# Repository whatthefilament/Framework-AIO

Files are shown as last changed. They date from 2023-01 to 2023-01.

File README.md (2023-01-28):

# Framework-AIO
3D Printable Case for Framework Laptop that converts it into an AIO style Desktop Computer

I've used as many OEM Framework parts as possible.

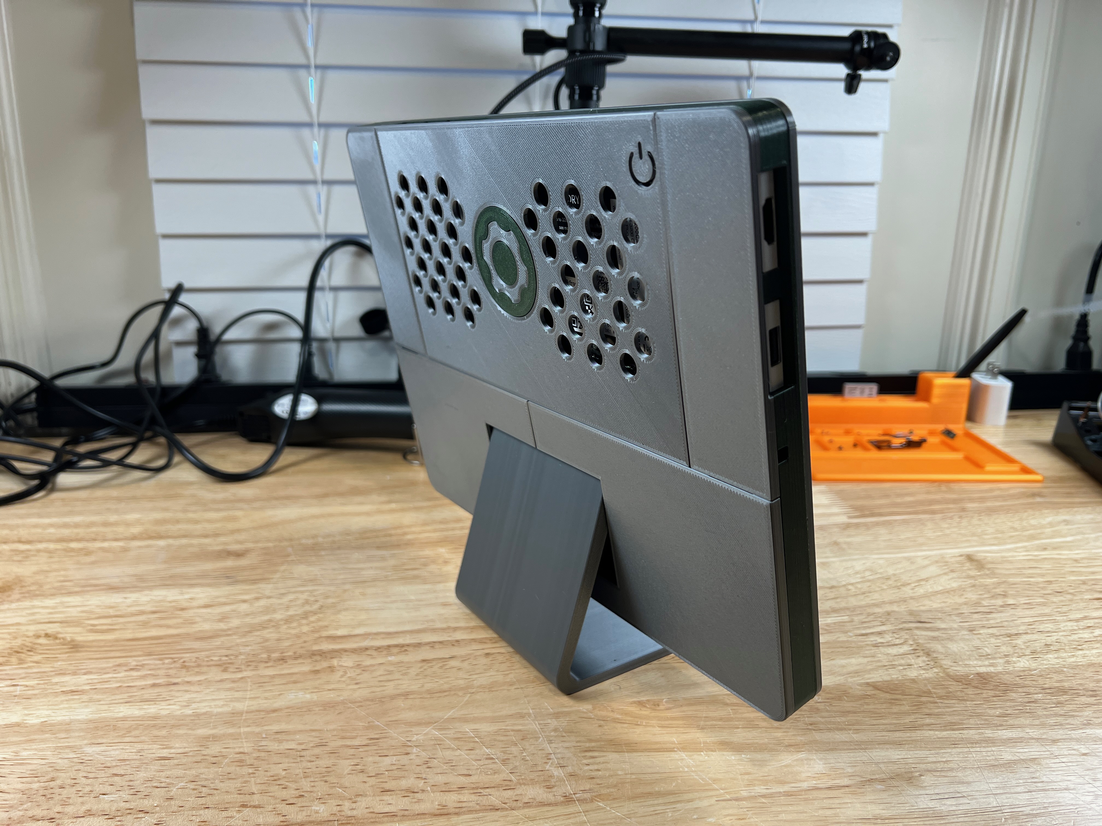
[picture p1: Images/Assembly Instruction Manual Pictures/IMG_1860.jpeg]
Side


## Assembly

[Build Instructions](https://www.instructables.com/Framework-AIO-Assembly/)

To help organize parts for this project, feel free to check out my [Framework parts tray](https://www.printables.com/model/253099-framework-parts-tray)

For assembly, you will need the following:

- 14 - M3 heat inserts (short)
- 10 - M3 x 4mm screws
- 4 - M3 x 8mm screws
- 1 - M2 x 6mm Self tap Screw
- 30 - 6mm x 3mm Magnets

- A small mallet/hammer to press in magnets (They are designed to be tight)
- M3 hex key
- Small head Phillips screwdriver (the one that comes with the Framework laptop works great)
- Soldering iron or other similar heat press insert tool
#
From the laptop itself you will need the following:

- Mainboard
- Expansion Cards
- Audio Board
- Wi-Fi Module
- Wi-Fi Antenna (Highly recommended that you buy a new one from Framework for the build, the antennas are very thin and break easily when attempting to remove from the display housing)
- Speakers
- Display
- Webcam and webcam ribbon cable
- Display Hinge (Specifically the left one with the L stamped onto it) I havent tried the new high weight hinges so I don't know if they work. I designed using the original hinges.
#
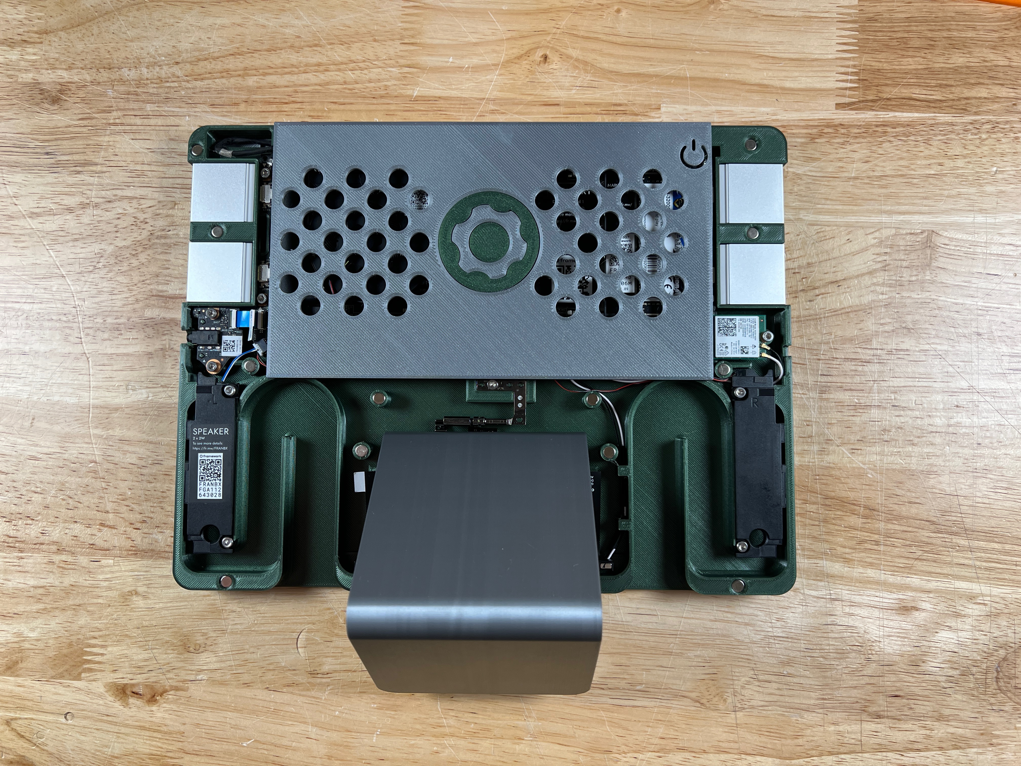
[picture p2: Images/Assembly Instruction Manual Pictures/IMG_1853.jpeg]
Open Back

#
## Print Settings:

I recommend printing all case parts of either ASA or ABS as this provides the best heat resistance. PETG may also work but I have not fully tested it. 

This case is designed to be printed at 0.2mm layer height with a 0.4mm nozzle.

No printed supports are needed. All holes have built-in supports. STLs are properly oriented for correct printing.

The main case has an overall dimension is 301.15mm x 231mm x 21. 

Thought many of the parts can be printed on a smaller printer. The main chassis and bezel will need a printer that can accommodate at least 301mm. 

## Mounting Options

In addition to the stock desk stand i've also included a 75mm VESA mount option for mounting on monitor arms.

I've uploaded the step files for the model as well, feel free to modify the design however you'd like. 

#
<br />This work is licensed under a <a rel="license" href="http://creativecommons.org/licenses/by-nc-sa/4.0/">Creative Commons Attribution-NonCommercial-ShareAlike 4.0 International License</a>.
#
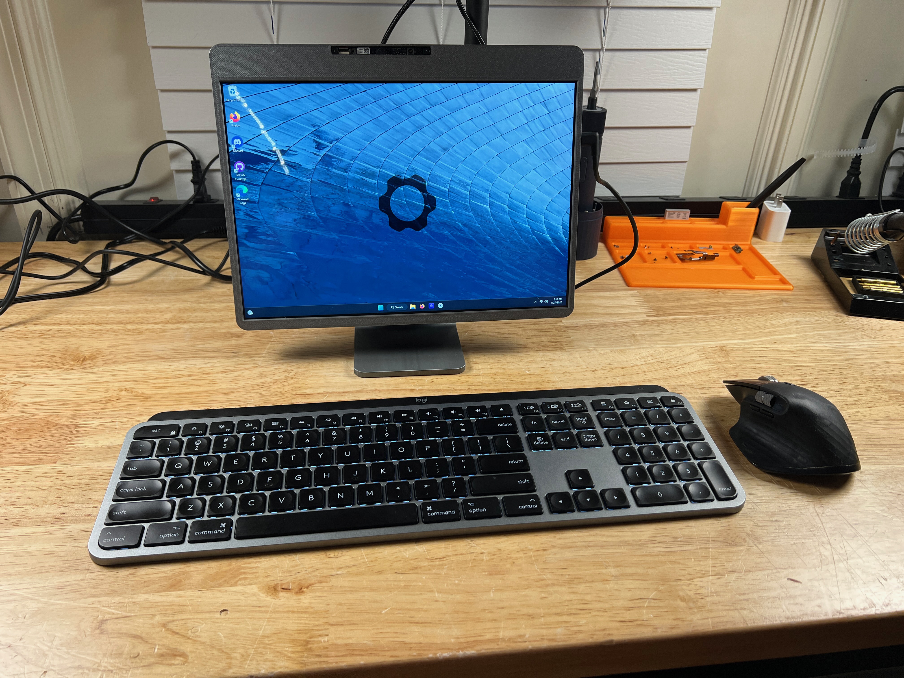
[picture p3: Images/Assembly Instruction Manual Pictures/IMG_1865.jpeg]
Running

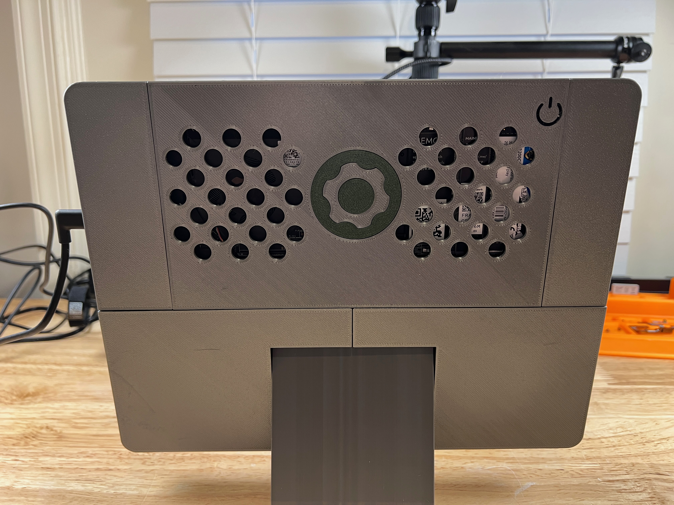
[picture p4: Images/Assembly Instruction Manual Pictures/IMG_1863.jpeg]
Back

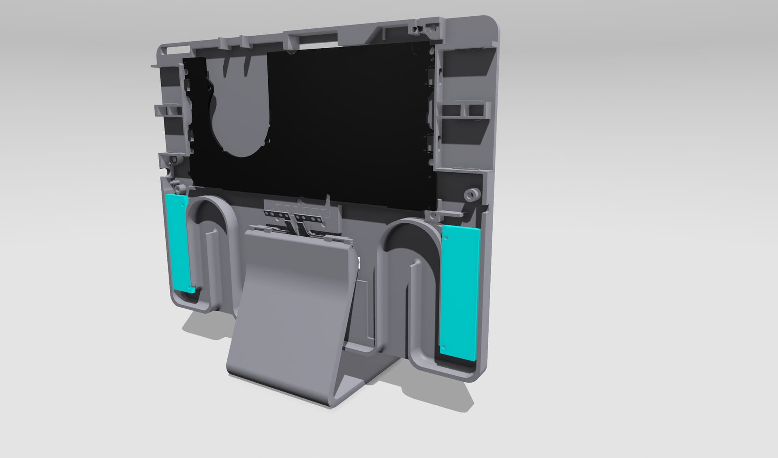
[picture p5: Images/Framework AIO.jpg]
Back Render

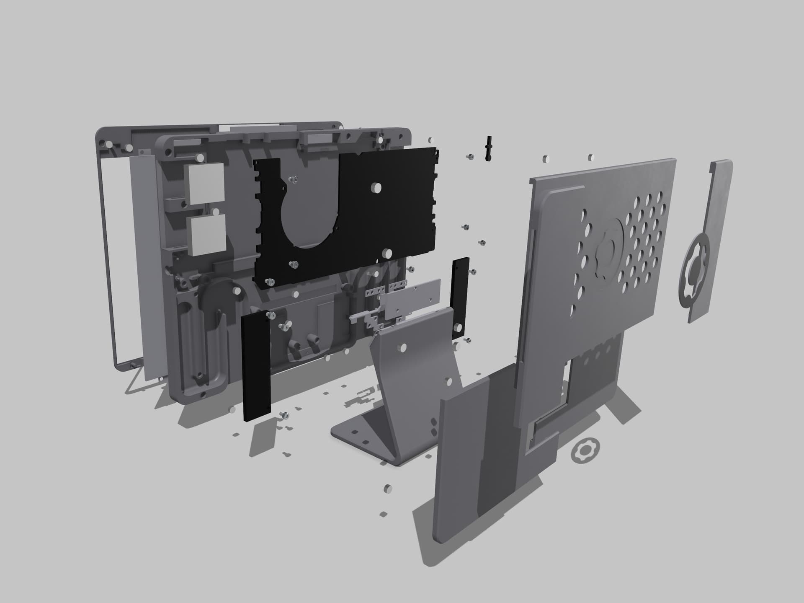
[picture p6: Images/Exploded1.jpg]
Exploded 1

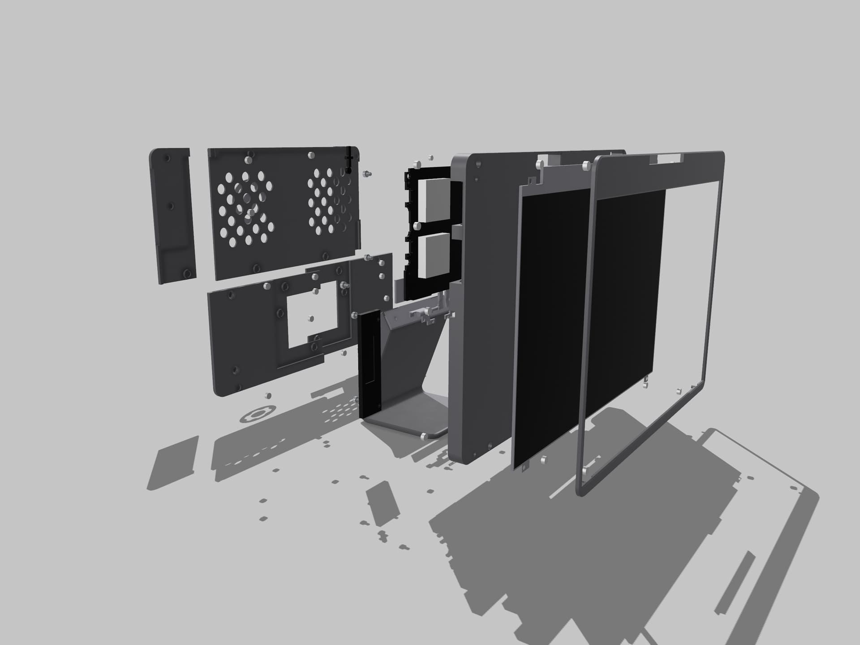
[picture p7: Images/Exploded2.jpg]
Exploded 2


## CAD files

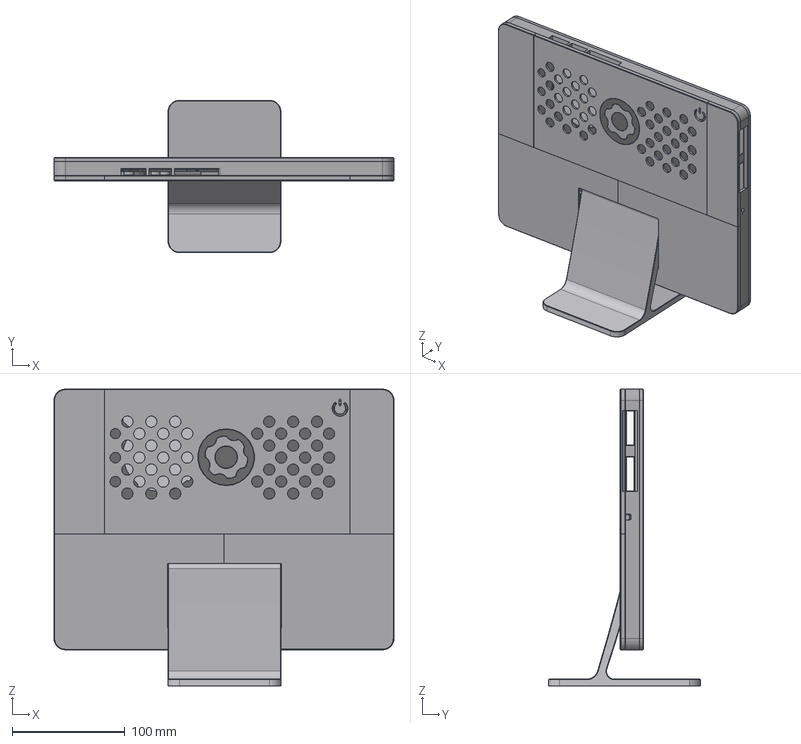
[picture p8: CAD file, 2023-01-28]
STEP/Framework AIO.step
301.2 x 135.0 x 262.9 mm
Back Panels
Stand
Back Panel Magnets (1)
Back Panel Magnets
Display Magnets
Hinges
Expansion Cards
Speakers

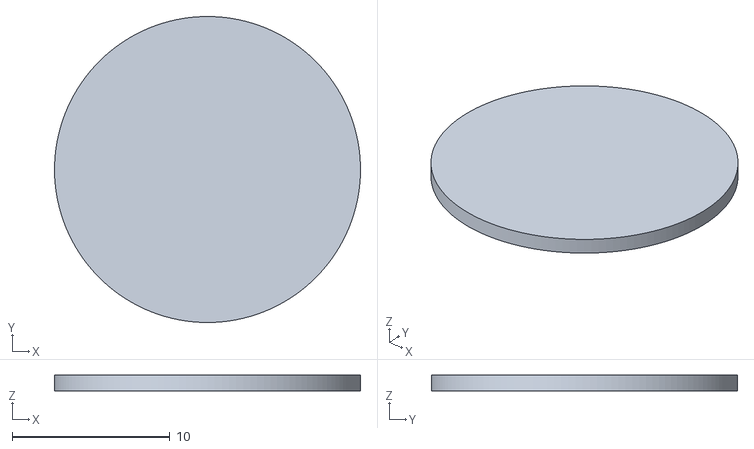
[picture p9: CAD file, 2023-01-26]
STLs/Back Panel/Logo Inner.stl
19.4 x 19.4 x 1.00

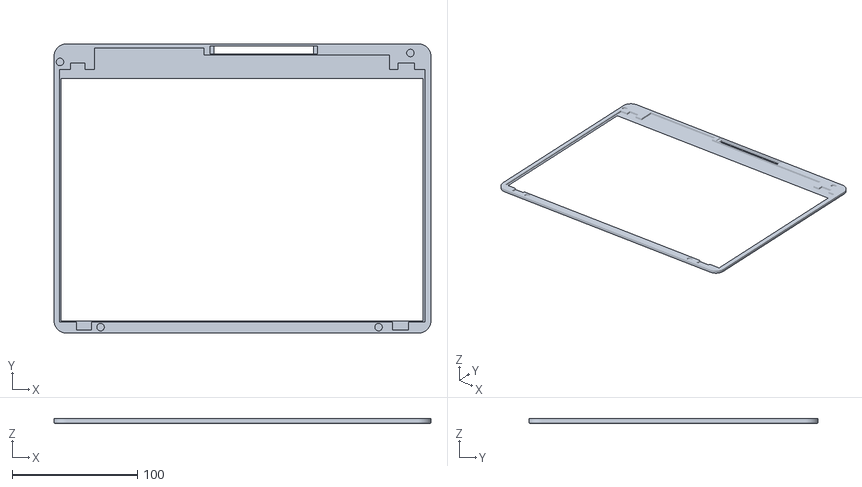
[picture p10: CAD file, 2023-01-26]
STLs/Display Bezel.stl
301.1 x 231.0 x 3.60

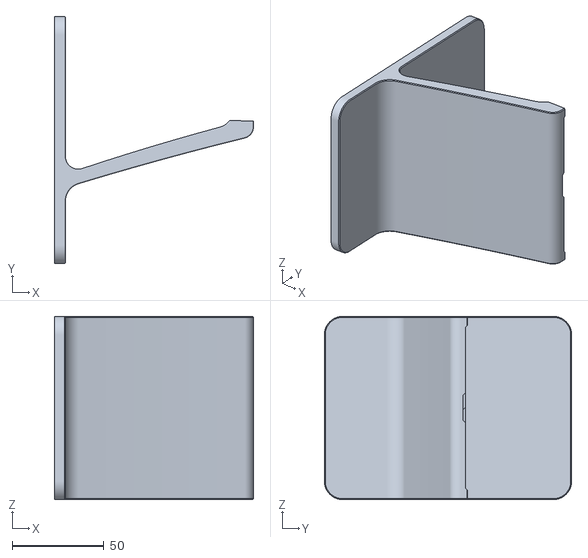
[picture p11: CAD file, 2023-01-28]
STLs/Stand Options/Desk Stand.stl
108.6 x 135.0 x 100.0

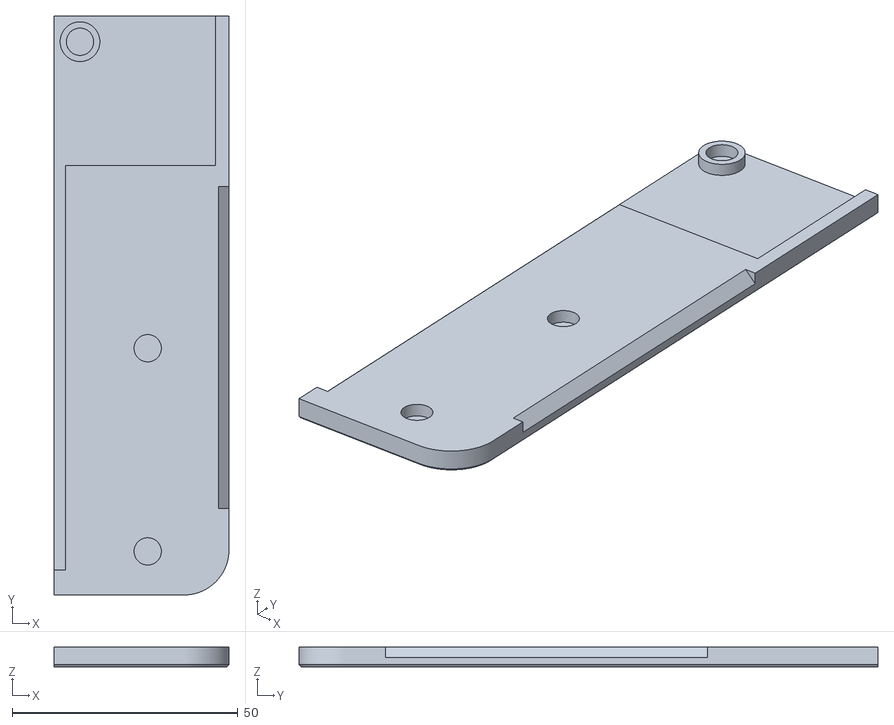
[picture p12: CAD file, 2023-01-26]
STLs/Back Panel/Upper Right Panel.stl
38.8 x 128.3 x 4.40

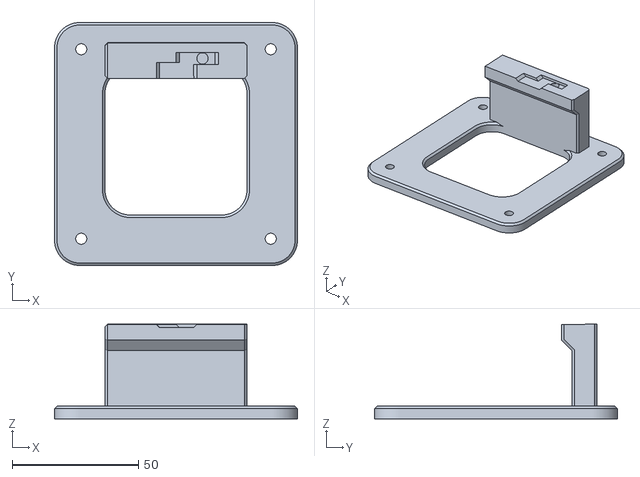
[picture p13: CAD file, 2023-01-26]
STLs/Stand Options/75mm VESA Mount.stl
96.2 x 96.2 x 37.4

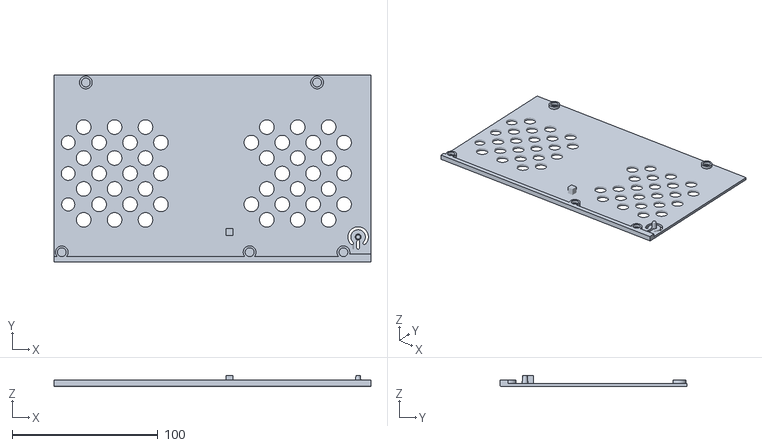
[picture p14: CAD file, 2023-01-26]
STLs/Back Panel/Center Panel.stl
217.5 x 128.3 x 7.50

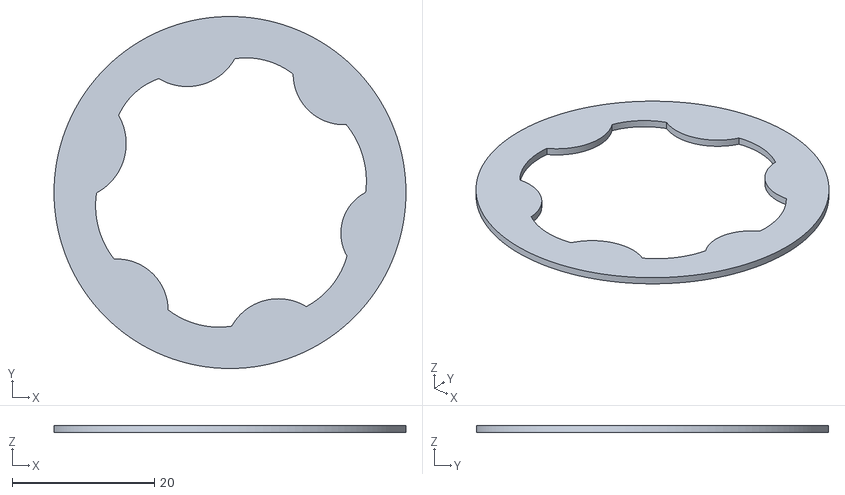
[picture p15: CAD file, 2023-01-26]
STLs/Back Panel/Logo Outer.stl
49.4 x 49.5 x 1.00

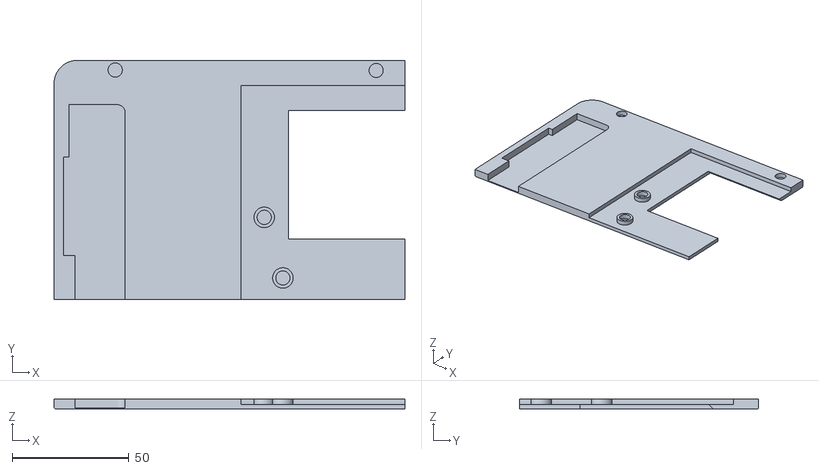
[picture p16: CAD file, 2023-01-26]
STLs/Back Panel/Lower Left Panel.stl
150.5 x 102.6 x 4.40

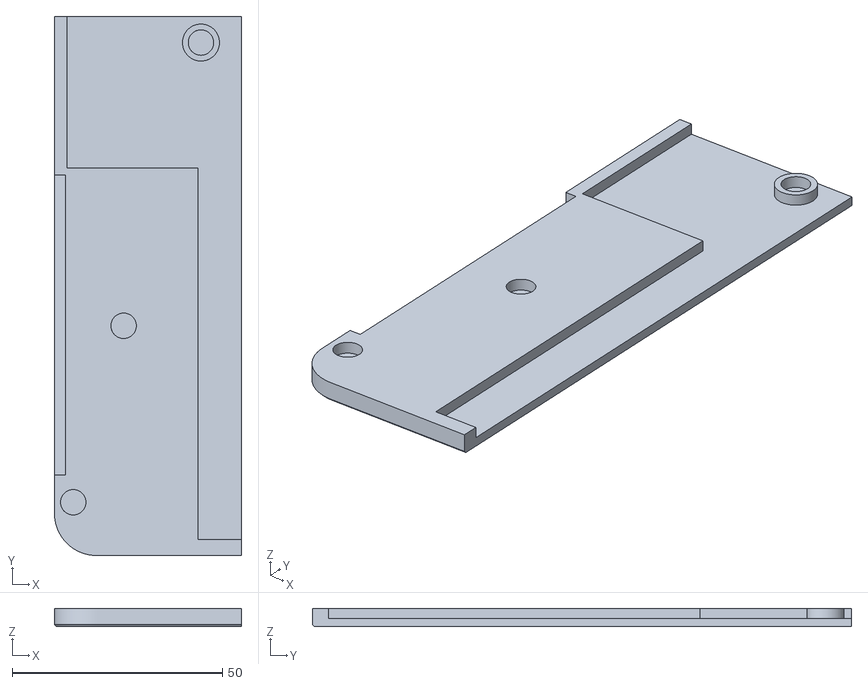
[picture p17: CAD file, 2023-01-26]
STLs/Back Panel/Upper Left Panel.stl
44.5 x 128.3 x 4.40

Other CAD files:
STLs/Back Panel/Lower Right Panel.stl

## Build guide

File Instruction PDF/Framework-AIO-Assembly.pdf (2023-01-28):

instructables

Framework AIO Assembly (http://www.instructables.com/Framework-AIO-Assembly/)

by whatthefilament (http://www.instructables.com/member/whatthefilament/)

3D Printable Case for Framework Laptop that converts it into an AIO style Desktop Computer

Supplies:
To help organize parts for this project, feel free to check out my [Framework parts tray] (https://www.printables.com/model/253099-framework-parts-tray)

For assembly, you will need the following:

- 14 - M3 heat inserts (short)
- 10 - M3 x 4mm screws
- 4 - M3 x 8mm screws
- 1 - M2 x 6mm self tapping screw
- 30 - 6mm x 3mm Magnets
- A small mallet/hammer to press in magnets (They are designed to be tight)
- M3 hex key
- Small head Phillips screwdriver (the one that comes with the Framework laptop works great)
- Soldering iron or other similar heat press insert tool

From the laptop itself you will need the following:
- Mainboard
- Expansion Cards
- Audio Board
- Wi-Fi Module
- Wi-Fi Antenna (Highly recommended that you buy a new one from Framework for the build, the antennas are very thin and break easily when attempting to remove from the display housing)
- Speakers
- Display
- Webcam and webcam ribbon cable

Framework AIO Assembly: Page 1

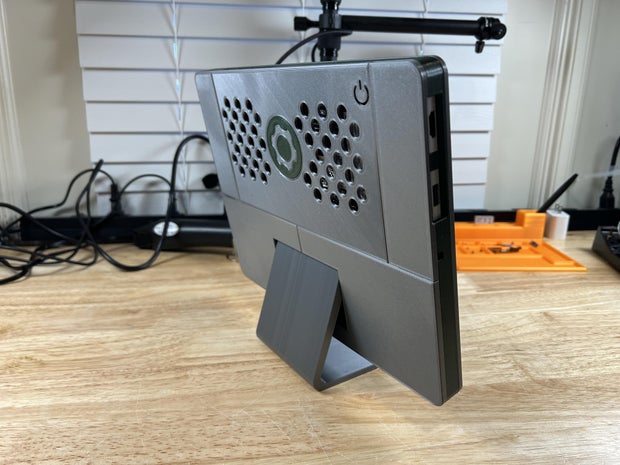
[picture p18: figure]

Step 1: Heatset Inserts
- Display Hinge (Speci<cally the left one with the L stamped onto it) I havent tried the new high weight hinges so I don't know if they work. I designed using the original hinges.

Using a soldering iron or other tool capable of setting a heat set insert place the 14 heatset inserts. ( 13 in the main chassis and 1 in the desktop stand. See each location highlighted in the images above.

Step 2: Magnets

Using 30 6x3mm magnets set a magnet in each of the highlighted spots from the images above.
Please remember to keep polarity in mind. When attaching the display bezel and back panelsthe polarity needsto be correct so that they aren’t repelled.
Note, each magnet mounting spot is designed to be snug enough that the magnets will hold in with friction. Depending on your printer you may need to add a dab of glue if the magnet doesn’t hold in place on its own.

Step 3: Add Display Panel and Webcam

Set the display panel face down into the bezel. Ensure each of the 4 tabs line up and sit properly in the frame.

After placing the display we will add the webcam module. To get correct orientation from the webcam output you will need to place it so that ribbon cable is point towards the top of the bezel and rapped back around.
If placed with the ribbon cable facing down the camera feed will be upside down and I haven’t found a way in Windows to rotate it.

Once placed in the bezel bend and route the ribbon cable as shown in the picture above. This will leave enough slack to connect the cable to the mainboard while not <lling up the back compartment with unnecessary cable.

Step 4: Attach Display to Chassis

Once the display and webcam are properly set in the bezel. Run the webcam cable in display cable through the holes highlighted above.

After pulling the cables through align the magnets and set the chassis down of the display. Everything should snap into place.
If the bezel doesn’t sit Bush you just need to pull the cables a little to get them to sit in their channels. There is not a lot of spare room so just play around with them till it sits right.

Step 5: Add Mainboard and Expansion Cards

Once everything is properly situated with the display bezel. Set the mainboard in the chassis as shown above making sure to align the audio board with its mounting studs. Everything should <t snug in place.

Before screwing down the mainboard. I suggest plugging in your expansion cards. They will help make sure everything is properly aligned.
If you’re struggling to get the expansion cardsto plug in feel free to cut out the alignment rails along the sides of each expansion slot on the chassis. They are designed to allow the expansion cardsto slide into the chassis asthey do in the laptop but depending on your printer calibration they can be tough. With them removed it becomes much easier to plug in the cards. They are just a bit looser and have the potential to harm the USB C slot mounted to the mainboard if torqued the wrong way.

After adding the mainboard and plugging in the expansion cards go ahead and screw down the mainboard, audio board and Wi-Fi module with the 8 M3x4mm screws highlighted in the picture above.

Step 6: Add Wi-Fi Antenna

Before setting the Wi-Fi antenna in the chassis. Start the M2x6mm self tapping screw to the middle antenna hole. Before screwing it into place route the antenna wiresthrough the retainers asshown in the picture above.

With the wires run you can now set the antenna module in place and screw fasten it.

After you fasten it, connect the white and black wires to their respective pins on the WiFi module. Be careful, the pins are delicate.

After all steps above are done, route the antenna wire slack as shown in the picture above to keep it safe and out of the way.

Step 7: Speakers

With the Wi-Fi installed and out of the way. We can now move on to the speakers.
Set the speakers into the chassis as show, each speaker is held in place with 2 M3x8mm bolts.
DO NOT OVER TIGHTEN THE SCREWS. THEY HAVE RUBBER GASKETS THAT WILL MANAGE VIBRATION. THE SCREWS ONLY NEED TO BE TIGHTENED DOWN ENOUGH SO THEY CLEAR THE BACK PANELS.
With the speakers mounted, run the cables as shown in the picture above and connect the speaker cable to the mainboard.
Ensure the speaker cable runs above the hinge mount but below the mainboard to keep from getting caught in the hinge.
Using a spudger or other similar tool (the framework screwdriver works great) push the wire coming out of the speaker on the right down below the speaker. We don’t want it to get caught between the chassis and panel when being snapped into place.

Step 8: Display Mount

At this point, all electrical components are installed in the chassis and we can move on to the display mount.

You can choose to use either the desk stand or the VESA mount. For this assembly, we will be using the desk stand.

Screw the hinge into the stand using an M3x4mm bolt as shown in the picture above. We want to start with the stand as we won't be able to access this side of the hinge when mounting in the case.

After it is attached, align the other side of the hinge with its mounting point in the center of the chassis and secure it in place with the last M3x4mm bolt.

Step 9: Back Panels

At this point, we have a functional computer but we still want it to look nice, so we can simply add the panels to the back letting the magnets align each panel into place with a satisfying snap! If you decided to print an accent inlay for the logo now would also be a good time to glue it into place.

Step 10: First Boot

We now have a beautifully assembled computer. Great job!

You can plug in any suGciently powered USB-C cable to power the machine. Using the power button located on the back the machine will boot.

The only problem we have now is the display will be upside down. To <x this we can simply go into the settings menu on windows, display settings and set the orientation to Bipped.

Step 11: Complete!

Great job! You have completed the assembly of your Framework AIO. I hope you like it! Let me know if you have any suggestions or improvements I can make to future iterations.

Special thanks to HJA for her help!

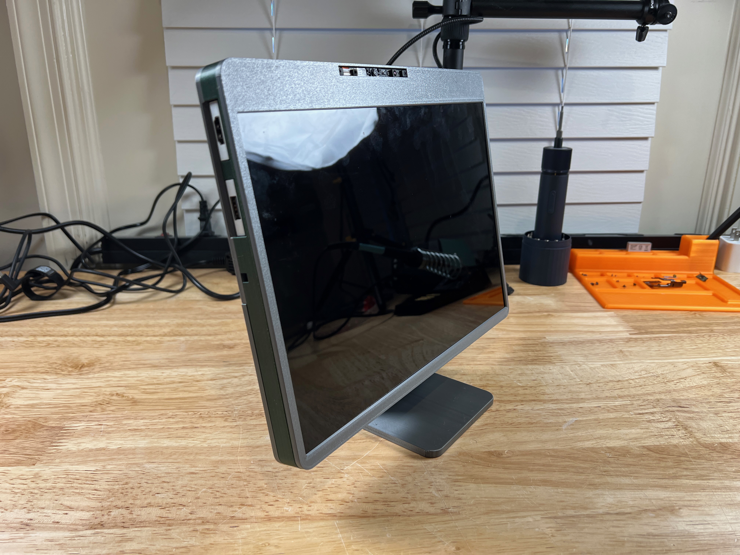
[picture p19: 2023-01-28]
Images/Assembly Instruction Manual Pictures/IMG_1859.jpeg

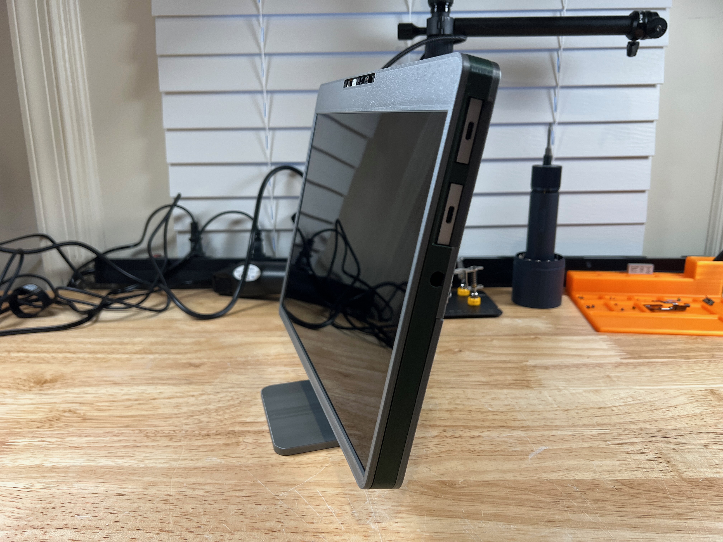
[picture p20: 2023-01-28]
Images/Assembly Instruction Manual Pictures/IMG_1862.jpeg

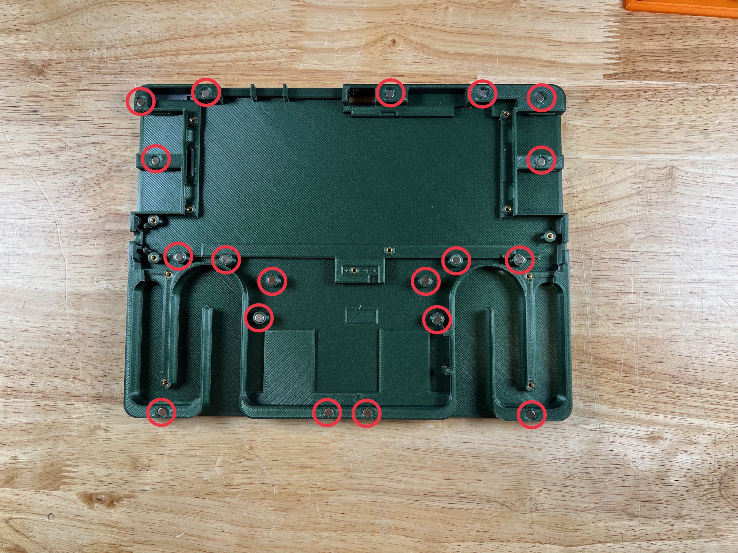
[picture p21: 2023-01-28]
Images/Assembly Instruction Manual Pictures/IMG_1828.jpeg

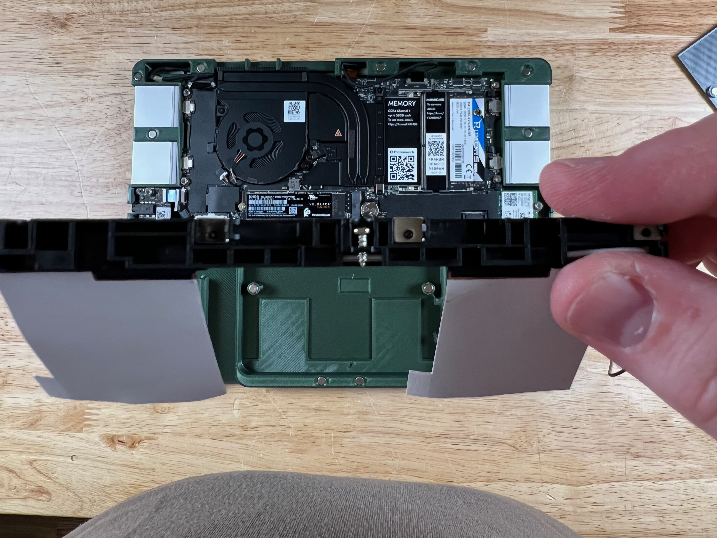
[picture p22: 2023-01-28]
Images/Assembly Instruction Manual Pictures/IMG_1845.jpeg

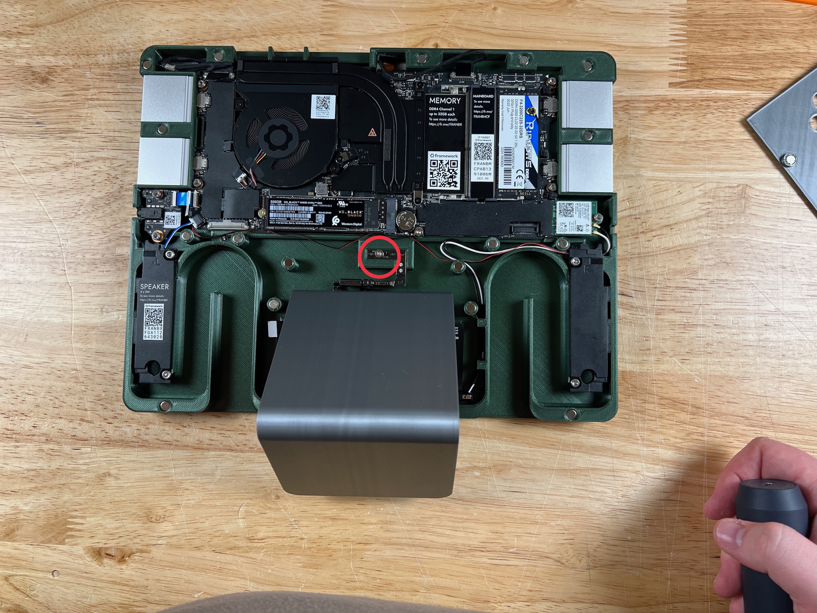
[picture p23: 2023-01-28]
Images/Assembly Instruction Manual Pictures/IMG_1851.jpeg

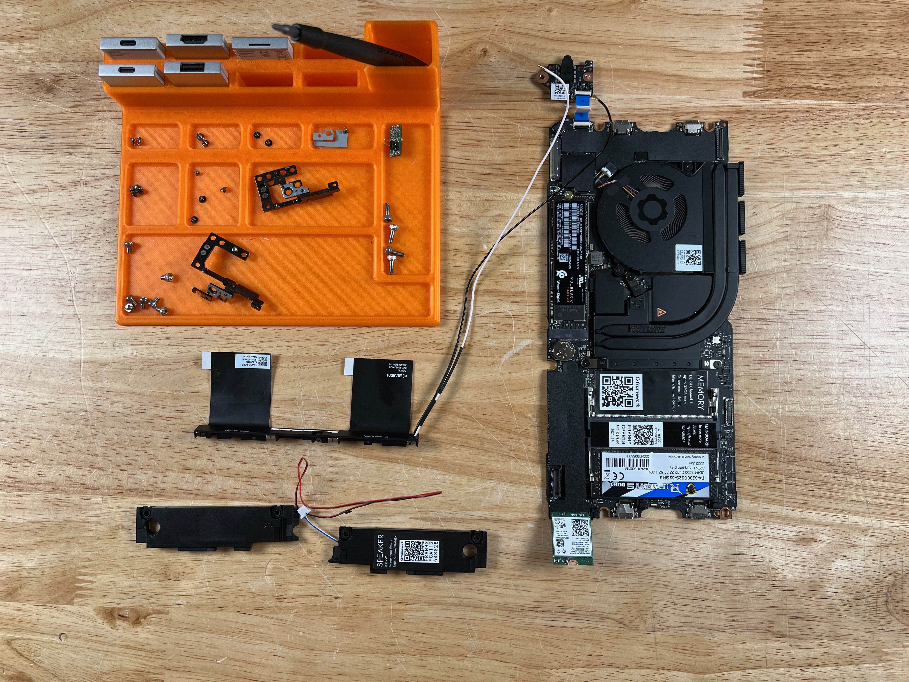
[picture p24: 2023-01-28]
Images/Assembly Instruction Manual Pictures/IMG_1827.jpeg

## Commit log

2023-01-26 STL printing orientation
    [75mm VESA Mount.stl, Center Panel.stl, Desk Stand.stl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]
2023-01-27 New Desk Stand
    [Desk Stand.stl, Framework AIO.step]
2023-01-28 Fixed Stand STL Orientation
    [Desk Stand.stl, Framework AIO.step]
